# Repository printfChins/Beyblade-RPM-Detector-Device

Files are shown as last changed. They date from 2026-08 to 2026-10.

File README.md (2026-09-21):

(BETA)BRD_0 91OLED_402030_V3 v9

## Beyblade RPM Detector Device

Open-source firmware.

## Flash Download Tool

https://github.com/printfChins/Web-Flash-Download-Tool/tree/main

## Web Interface

Use the BRD Web interface here:

https://printfchins.github.io/BRD-Web/

---

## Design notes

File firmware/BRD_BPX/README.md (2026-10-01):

# BRD_BBPX — LOAD / AUTO 雙模式版

修訂識別：`BRD_BBPX_AUTO`，2026-09-25。以原 `BRD_BBPX` 的 BBPX BLE 協議、單圈曲線與 OLED 圖示為基礎，新增可由 `brd_config.h` 選擇的 **LOAD / AUTO 量測模式**。預設維持 LOAD，避免既有行為在未改 CFG 時改變。

## 開啟與替換方式

完整解壓縮後，以本包的 `BRD_BBPX/` 替換舊專案資料夾，Arduino IDE 開啟 `BRD_BBPX/BRD_BBPX.ino`。根目錄全部 `.cpp/.h` 與 `.ino` 放在同一層。主程式沒有新增片段，不需手動貼入程式。

- Arduino-ESP32 3.3.11；NimBLE-Arduino 2.5.1。
- ESP32C3 Dev Module；CPU 80 MHz；Flash 4 MB、DIO、80 MHz；Default Partition。
- 本次原始碼已變更，但目前環境沒有 Arduino-ESP32 完整編譯工具鏈，因此已移除舊 R4 `.bin`，避免誤燒未包含 AUTO 的舊韌體。
- 請以本包原始碼重新編譯；若要保留 NVS 歷史，停用 Erase All Flash Before Sketch Upload。

## 新增、修改與刪減

| 標記 | 內容 |
|---|---|
| 新增 | `BRD_MEASUREMENT_MODE_LOAD` / `BRD_MEASUREMENT_MODE_AUTO` 與單一 `AUTO_RPM_THRESHOLD=2000`。 |
| 新增 | AUTO 有效歸零：最後有效 RPM < 2000，之後 0 RPM 持續 250 ms。 |
| 新增 | AUTO 有效發射：曾達 RPM >= 2000，之後 0 RPM 持續 1000 ms。 |
| 修改 | AUTO 不掛 LOAD interrupt，也不以 LOAD GPIO 決定開始、發射或歸零。 |
| 修改 | AUTO 的 A0 `loaded` bit：即時 RPM != 0 為 1，RPM == 0 為 0。 |
| 修改 | AUTO OLED 第一行固定 `AUTO READY`；HOLD 仍具有最高顯示優先權。 |
| 保留 | BBPX 既有 32 點單圈曲線格式、Service/Characteristic UUID、17-byte CMD/Notify 封包與 History 格式。 |

本次主要修改 `brd_config.h`、`brd_measurement.cpp`、`brd_oled.cpp`，並新增 AUTO 宿主測試。詳細差異見 `docs/BRD_BBPX_AUTO_MODE.patch`.

## 量測模式設定

模式集中在 `BRD_BBPX/brd_config.h`：

```c
#define BRD_MEASUREMENT_MODE_LOAD         0U
#define BRD_MEASUREMENT_MODE_AUTO         1U
#define BRD_MEASUREMENT_MODE              BRD_MEASUREMENT_MODE_LOAD
#define AUTO_RPM_THRESHOLD                2000U
#define AUTO_LAUNCH_ZERO_MS               1000UL
#define AUTO_RESET_ZERO_MS                250UL
```

| 模式 | READY / 發射來源 | 有效歸零 | 有效發射 | BLE A0 loaded | OLED |
|---|---|---|---|---|---|
| LOAD | LOAD GPIO | 原本 LOAD/timeout 流程 | LOAD HIGH->LOW | 實體 LOAD | `WAIT LOAD` / `LOADED READY` |
| AUTO | RPM-only | `<2000 RPM` 後 0 RPM >=250 ms | 曾 `>=2000 RPM` 後 0 RPM >=1000 ms | RPM!=0 -> 1；RPM==0 -> 0 | `AUTO READY` |

AUTO 達到 2000 RPM 後，250 ms 歸零只會讓即時 RPM 回到 0，不會清掉發射候選；要等 1000 ms 靜止滿足才封存 Shot。AUTO 的 MAX/HOLD 行為沿用 V1.17：完成後顯示 MAX，HOLD 結束仍保留 MAX，直到下一次 RPM 真正開始才清除。

BBPX 協議沒有獨立的「Launch RPM」欄位，因此 AUTO 不新增也不傳送額外發射點 RPM；既有 History 代表值仍維持整次量測 MAX RPM 的 BBPX 測試映射。

## 曲線規則

| 裝載後事件順序 | 本次固定參考 | 每筆曲線的整圈週期 |
|---|---|---|
| 正緣先觸發 | 正緣 | 本次正緣時間－前次有效正緣時間 |
| 負緣先觸發 | 負緣 | 本次負緣時間－前次有效負緣時間 |

第一個參考事件只建立基準；下一個有效同類事件取得整圈週期後，立即記錄。初始 GPIO 電位不決定參考，第一個有效 RPM 來自哪邊也不會改選。同一次量測固定使用相同參考；重新裝載或既有量測重置後才重新選擇。

兩種邊沿仍各用自己的整圈時間計算 `RPM = floor(60000000 / period_us)`。曲線只記錄參考邊沿的 `raw = round(period_us / 8)`，保存前 32 個有效完整週期，尾端補零；第 33 圈之後仍可更新 MAX。發射時保留裝載後的前段曲線。

範例：正緣先到，正緣週期 6000 us、負緣週期 8000 us。即時 RPM 仍會依序更新 10000、7500；曲線只保存正緣的 raw 750，每圈一筆。若負緣先到，則全程保存負緣週期。

連續有效取樣時，32 點代表 32 圈，逐點累加 `raw / 125.0` 得到毫秒時間軸，不再重複累加同一圈。週期仍有 8 us 量化；停頓、被丟棄的無效資料與 raw 飽和不會自動補成絕對時間戳。詳 `docs/SINGLE_REV_REFERENCE.md`。

History 代表 SP 保留整次雙邊沿 MAX RPM 的 BRD 測試映射，可與所選單圈曲線峰值不同，不宣稱等同原廠 SP 評分。發射後完成與至少 600 ms 的發布下限、32 格容量、17-byte BLE 封包均沿用。

## OLED 藍牙圖示

[修改] 完整採用附件 `BRD_BLE_OLED/brd_oled.cpp` 的 `oled_draw_bluetooth_icon()`。圖示為 7×13，位於 x119..125、y17..29；已建立 BLE 連線時顯示，斷線重畫時清除。五位 RPM/MAX 的最右像素為 x105，圖示不遮住文字、HOLD、電池或充電圖示。

預覽在 `docs/OLED_BLE_R4_Preview.png`，左為 R3，右為 R4。影像由實際繪圖函式輸出 framebuffer 後放大，不是 OLED 實板照片。本次已逐點比對，圖示輸出與附件相同。

## API 判定

LOAD 模式沿用原報告相同 30 項條件與 R3 判定：**29 項符合、0 項部分符合、1 項不符合**。AUTO 是 BRD 新增模式，不納入該原協議符合性統計。第 24、26 項已恢復單圈資料與前 32 圈語意；第 27 項原建議「發射後起錄」，本版依你的要求保留「裝載後取得有效週期就起錄」。詳細比對在 `docs/BRD_BBP_API_Conformance_Review.md`。

註解：既有 NVS 曲線不重算，格式沒有 R2／R3 取樣模式欄位；R3 起的新 Shot 採單圈曲線，R4 沿用此規則。

## BLE 與 CMD

| 項目 | 值 |
|---|---|
| 名稱 | `BEYBLADE_TOOL_BRD_XXXX`，`XXXX` = ESP32 eFuse MAC 最後 2 bytes 的四位大寫 HEX |
| Service | `55c40000-f8eb-11ec-b939-0242ac120002` |
| 共用特徵 | `55c4f002-f8eb-11ec-b939-0242ac120002` |
| 特徵屬性 | Notify、Write、Write Without Response |
| 封包 | 固定 17 bytes，多 byte 值為 Little Endian |
| TX 功率 | 0 dBm |

Service 放主廣播，完整名稱放 Scan Response。裝置啟動時使用 `esp_efuse_mac_get_default()` 讀取 ESP32 eFuse MAC，名稱尾碼四碼取 MAC 最後 2 bytes，例如尾碼 `0x126A` 時名稱為 `BEYBLADE_TOOL_BRD_126A`。共用 F002 接收命令是本包實作，原廠 Write UUID 仍未完全確認。

| 一個 byte 命令 | 行為 |
|---|---|
| `0x51` | 回傳一頁 A0。 |
| `0x74` | 依序送 B0~B7、70~73 共 12 頁；可重讀最新完整 Shot。 |
| `0x75` | 清除 RAM 歷史、曲線、MAX、Counter，作廢目前 Capture，安排保存；不增加自創 ACK。 |
| `0x61`／未知 | 安全忽略，不改資料。 |

預設 `BBP_COMPAT_AUTONOTIFY=1` 同時支援命令與事件通知：訂閱穩定 100 ms 後送 A0，loaded 狀態改變送 A0，Shot 發布後送 12 頁。LOAD 模式 A0 byte3 bit2 仍跟隨實體 LOAD；AUTO 模式改為即時 RPM != 0 時為 0x04、RPM == 0 時為 0x00。主機即使每 500 ms 輪詢，也可維持相同封包解析。

`BBP_COMPAT_AUTONOTIFY=0` 只保留舊純輪詢及舊 flags 語意供回歸比對，**不符合預設模式的全部通知條件**。本包無固定每 500 ms 自動 Notify；10 ms 是待送頁面的排程間隔。

12 頁由一致快照產生，傳送中不插入另一批資料。Notify 提交失敗重試同一頁，持續 1.5 秒失敗斷線；32 筆命令佇列溢位也斷線。重新連線或訂閱不續傳舊批次。Notify 成功只表示交給 BLE stack，沒有應用層 ACK；缺頁由主機再送 0x74 整組重讀。

## 歷史與保存

最近 50 筆使用環形緩衝，輸出由舊到新。B6 offsets 7/9/11 分別為終身 MAX、累計次數、有效筆數；B7 byte16 是 B0~B6 的 16-byte payload 總和 mod 256。內部 Counter 為 uint32，BLE 欄位為 uint16，主機需處理 65535 後的回繞。

NVS 使用 `brd_bbp/history_v1`、181-byte version 1 blob 與 CRC32。保留長度、版本、CRC、數值範圍、環形索引及曲線尾端零值檢查；只移除曲線峰值必須等於代表 SP 的假設。舊版有效資料可以載入，既有曲線維持原內容，新收集規則從下一次 Shot 生效。若改回舊韌體，舊解碼器可能拒絕獨立代表值或空曲線的新資料；未承諾降版相容。

Flash 僅在既有安全時段保存。0x75 的 RAM 清除不表示 Flash 已寫入；寫入前突然斷電，尚未保存的結果或清除可能遺失。首次 NVS 載入失敗時不覆寫舊資料，BBP 暫停初始化並重試。無 BLE 連線仍可建立本地歷史。

## GPIO 與既有量測參數

| 功能 | GPIO／設定 |
|---|---|
| RPM IR | 3，INPUT、CHANGE；每次量測第一個觸發邊沿決定固定參考，正緣→正緣或負緣→負緣為一整圈 |
| LOAD IR | 1，INPUT、CHANGE、HIGH=裝載 |
| 電池 ADC | 0，470k/470k 分壓、單次換算 |
| 充電偵測 | 10，INPUT_PULLUP、LOW=充電 |
| 充電 LED | 8 |
| OLED | SDA20／SCL21、外部上拉、128×32 SSD1306 |

LOAD 模式使用 LOAD 穩定 100 ms 才切換；LOAD 只負責歸零與啟動檢測，RPM 開始後不再參與發射判定。BLE 曲線保存最早 32 筆非 0 RPM，MAX 持續獨立更新；即時 RPM 嚴格低於 MAX 的 20% 時完成發射，300 ms 無「本次參考極性」邊沿會把即時 RPM 視為 0。AUTO 模式使用 2000 RPM 單一門檻與 250/1000 ms 歸零/發射時間。兩種模式都保留 MAX 自鎖 2.5 秒、OLED 更新 100 ms、低電與 ADC 錯誤保護。Battery Raw 為 SOC 對應 0~250 的 BRD 映射，非原廠電池標定。

## 資料夾結構與驗證

| 位置 | 內容 |
|---|---|
| `BRD_BBPX/BRD_BBPX.ino` | Arduino 主程式 |
| `BRD_BBPX/*.cpp`、`BRD_BBPX/*.h` | 完整正式模組 |
| `BRD_BBPX/CHANGELOG.md` | 新增／修改／刪減及行號 |
| `BRD_BBPX/VALIDATION.md` | 本次實際測試、編譯結果與限制 |
| `BRD_BBPX/docs/` | API、單圈參考說明、30 項比對、歷史報告、差異與驗證日誌 |
| `BRD_BBPX/firmware/` | 燒錄檔說明；本次未附新 `.bin` |
| `BRD_BBPX/tests/` | 8 組宿主測試及硬體替身 |

完整檔名清單見 `FILE_MANIFEST.txt`。在專案資料夾執行 `python3 tests/run_host_tests.py`；使用 g++ C++17、ASan/UBSan。現為 8 組測試，新增 AUTO 量測回歸；這些測試包含真實協定、Session、量測與 BLE 排程程式，但硬體邊界使用替身，尚未執行實板、無線擷取及官方 App 驗證。

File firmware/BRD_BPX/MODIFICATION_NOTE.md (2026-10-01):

# BRD_BBPX Measurement Modification Note

## 修改檔案
- `BRD_BBPX/brd_config.h`
- `BRD_BBPX/brd_measurement.cpp`
- `BRD_BBPX/tests/test_dual_edge.cpp`
- `BRD_BBPX/BRD_BBPX.ino`
- `BRD_BBPX/README.md`
- `BRD_BBPX/VALIDATION.md`

## 2026-10-01 正/負緣先觸發固定參考

1. RPM GPIO 由 `FALLING` 改回 `CHANGE`。
2. LOAD 模式仍需 LOAD HIGH 穩定 100 ms 才啟動新一輪量測。
3. 量測啟動後，第一個實際 RPM 邊沿決定本次固定參考極性。
4. 若第一個事件為正緣，只使用「正緣 -> 下一個正緣」的完整一圈週期計算 RPM。
5. 若第一個事件為負緣，只使用「負緣 -> 下一個負緣」的完整一圈週期計算 RPM。
6. 同一輪量測中參考極性不會切換；另一極性不更新 RPM、MAX，也不加入 BLE 曲線。
7. 參考極性選定後，ISR 只將相同極性的事件放入 RPM Queue，避免 `CHANGE` 模式長期造成兩倍 Queue 流量。
8. BLE 曲線仍保存最早 32 筆有效 RPM 週期，32 點之後 MAX 仍繼續更新。
9. LOAD 在 SPINNING 後不參與發射判定，也不能重置 RPM/MAX/曲線。
10. LOAD 模式發射完成條件仍為即時 RPM 嚴格小於本次 MAX 的 20%。
11. RPM Queue overflow 時保留本次已選參考極性，只清除週期基準；下一個相同極性邊沿重新建立基準，第二個相同極性邊沿恢復 RPM。

## 未改變
- LOAD 狀態切換仍需穩定 100 ms。
- BLE Profile 容量仍為 32 點。
- MAX 與 32 點曲線仍獨立。
- 300 ms 無參考極性邊沿時，即時 RPM 仍歸零。
- 發射成功條件仍為 `current_rpm < max_rpm * 20%`。
- 先前的 RPM / LOAD Queue overflow 防止中途重置修正仍保留。

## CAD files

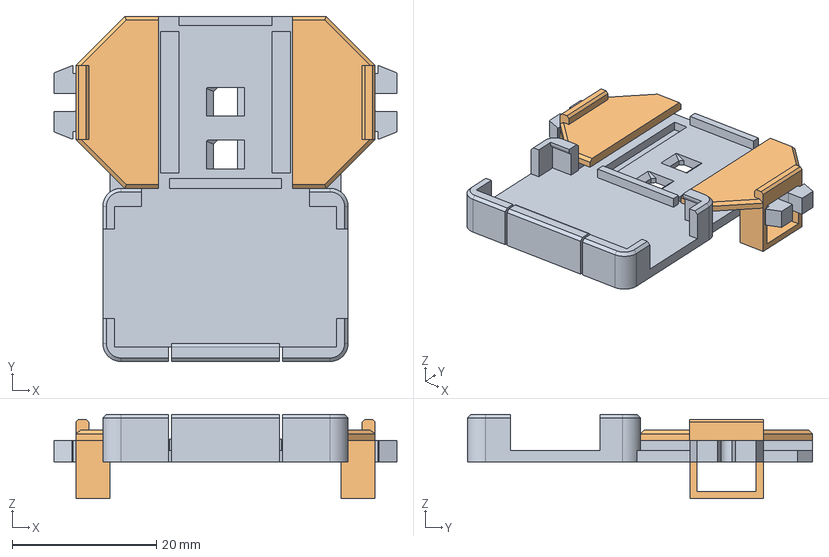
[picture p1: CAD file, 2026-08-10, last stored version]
3D Models/CAD/BRD 1.6mm底板厚度.step
47.5 x 47.8 x 11.7 mm

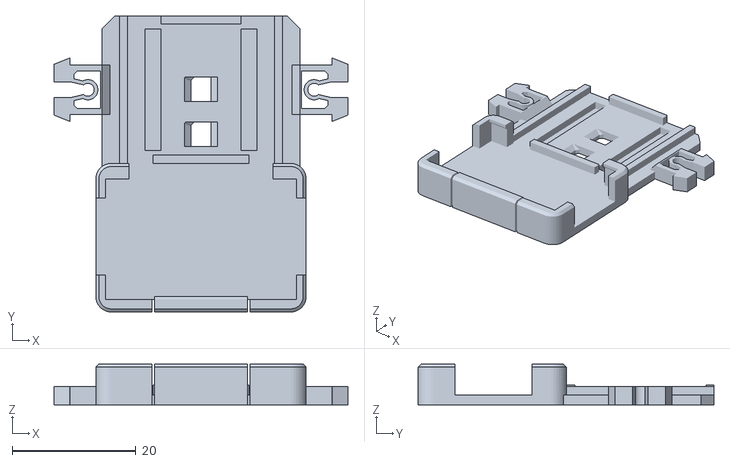
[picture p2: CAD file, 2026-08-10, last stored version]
3D Models/STL/BRD 1.6mm底板厚度_底板.stl
47.5 x 47.8 x 6.60

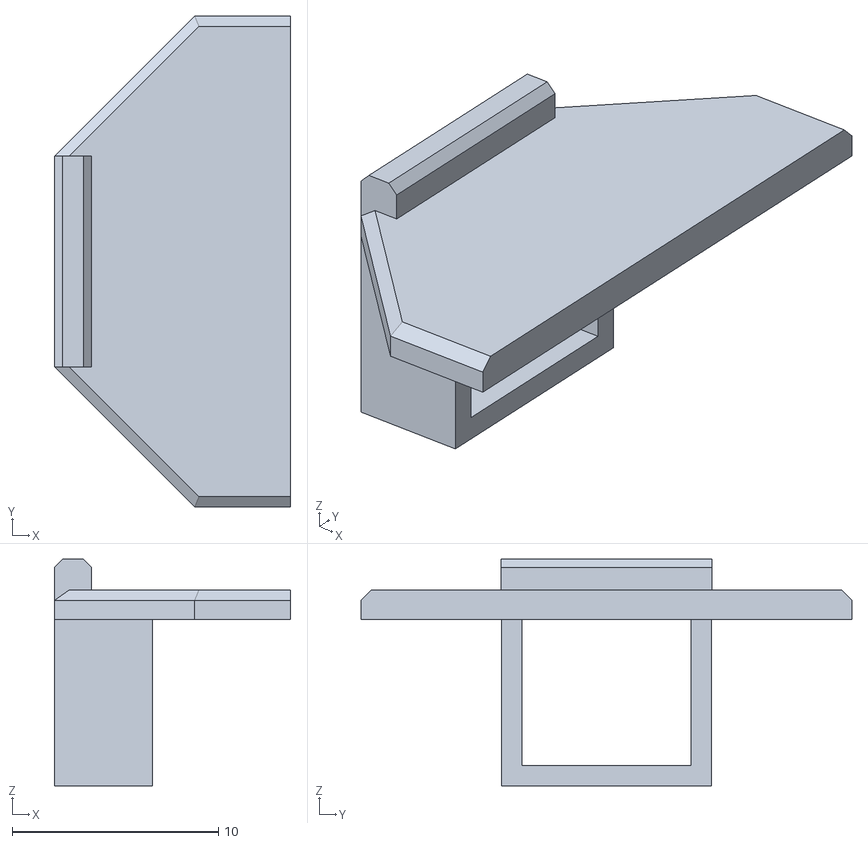
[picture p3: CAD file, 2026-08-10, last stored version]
3D Models/STL/BRD 1.6mm底板厚度_固定夾L.stl
11.4 x 23.8 x 11.0

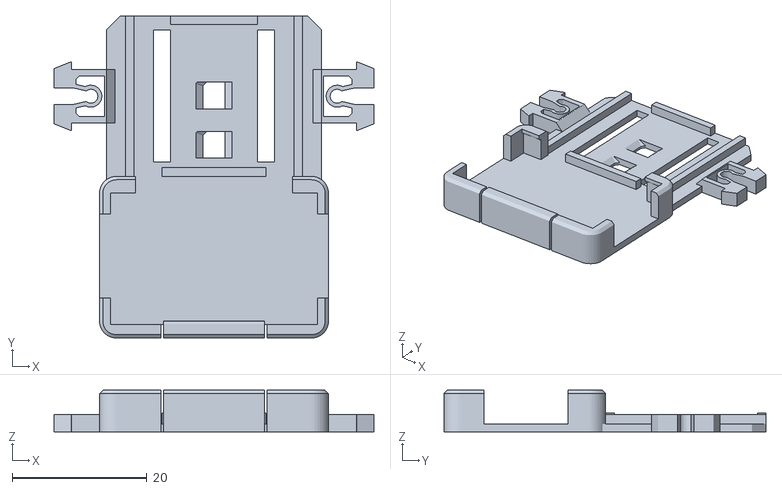
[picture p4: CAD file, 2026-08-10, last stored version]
3D Models/STL/BRD 1.2mm底板厚度_底板.stl
47.5 x 47.8 x 6.20

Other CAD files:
3D Models/STL/BRD 1.2mm底板厚度_固定夾L.stl
3D Models/STL/BRD 1.2mm底板厚度_固定夾R.stl
3D Models/STL/BRD 1.6mm底板厚度_固定夾R.stl

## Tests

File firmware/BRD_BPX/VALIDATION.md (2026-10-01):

# Validation

## 2026-10-01 First-edge reference / dual-edge input

Host regression tests were rebuilt and executed with `-Wall -Wextra -Werror` and ASan/UBSan.

Validated:
- RPM GPIO interrupt mode is `CHANGE`.
- After measurement is armed, the first actual RPM edge selects the reference polarity for that measurement.
- Rising edge first: only rising-to-rising periods calculate RPM.
- Falling edge first: only falling-to-falling periods calculate RPM.
- The opposite polarity does not update instantaneous RPM, MAX, or BLE profile points.
- The selected reference polarity remains fixed for the entire measurement.
- BLE profile still stores only the earliest 32 valid reference-period points.
- MAX continues updating from valid reference periods after the 32-point profile is full.
- RPM queue overflow does not abort the active capture; it preserves the selected reference polarity and rebuilds only the same-polarity period baseline.
- After the reference is selected, ISR filtering only queues that polarity, preventing `CHANGE` mode from permanently doubling RPM queue traffic.
- LOAD state still requires 100 ms stable time and does not reset an active SPINNING measurement.
- LOAD mode still finishes only when instantaneous RPM is strictly below 20% of MAX, including the normal 300 ms no-reference-edge path that sets RPM to zero.

Result: 8/8 host test binaries passed.

Limitations:
- Arduino/ESP32 firmware binary was not regenerated in this environment because Arduino-ESP32 build tools are not installed here.
- No hardware-in-the-loop test was performed.

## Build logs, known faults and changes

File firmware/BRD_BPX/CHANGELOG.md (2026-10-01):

# 2026-10-01 RPM 正/負緣先觸發固定參考

- [修改] `RPM_IR_TRIGGER_EDGE` 由 `FALLING` 改為 `CHANGE`。
- [新增] 每次量測第一個實際 RPM 邊沿決定固定參考極性。
- [修改] 正緣先到：只使用正緣 -> 正緣完整一圈計算 RPM。
- [修改] 負緣先到：只使用負緣 -> 負緣完整一圈計算 RPM。
- [修改] 另一極性不更新 RPM、MAX 或 BLE 曲線，且同一輪量測中不得切換參考極性。
- [修正] 參考選定後 ISR 只將相同極性送入 RPM Queue，避免 `CHANGE` 模式使 Queue 流量長期加倍。
- [保留] RPM Queue overflow 修正：保留既有曲線/MAX/參考極性，只重新建立同極性週期基準。
- [保留] LOAD 100 ms、SPINNING 後忽略 LOAD 發射判定、前 32 點 BLE 曲線、MAX 獨立更新、RPM < MAX 20% 發射成功。
- [驗證] rising-first、falling-first、固定參考、32 點/MAX、20% 門檻與 overflow 參考保持測試通過；8/8 host tests 通過。

# 2026-10-01 採樣中途重置 / Queue Overflow 修正

- [修正] `SPINNING` 後 LOAD HIGH/LOW 僅更新穩定狀態，不得重置 RPM、MAX 或 BLE 曲線。
- [修正] 只有 `WAIT_LOAD` 狀態下，LOAD 穩定 HIGH 100 ms 才能清零並啟動新一輪檢測。
- [修正] RPM ISR Queue overflow 不再呼叫 `brd_bbp_capture_abort()`，保留已取得的前 32 點與 MAX。
- [修正] RPM Queue overflow 後重新建立下降沿基準，禁止用 overflow 前後不連續的邊沿直接計算 RPM。
- [修正] RPM Queue overflow 事件回放期間暫停 inactivity timeout，避免誤觸發 300 ms 歸零/發射完成。
- [修正] LOAD Queue overflow 不再 `reset_measurement(false)` 或重新啟動整個 input capture；只重新同步目前 LOAD 電位並重新做 100 ms 去抖。
- [驗證] 新增 SPINNING LOAD 變化、RPM Queue overflow、LOAD Queue overflow 回歸測試；8/8 host tests 通過。

# 2026-10-01 LOAD 100 ms / 32 點發射判定

- [修改] 所有實體 LOAD 狀態切換需連續穩定至少 100 ms 才更新穩定狀態。
- [修改] LOAD 模式曲線由裝載後第一筆非 0 有效 RPM 開始；該筆 RPM 的邊沿類型成為固定單圈參考，固定保留前 32 點。
- [新增] LOAD 保持裝載且曲線達 32 點時，直接強制判定發射成功並封存。
- [修改] LOAD 已穩定切為非裝載且曲線未滿 32 點時，RPM 降至本次 MAX 的 20% 以下完成發射；300 ms 無脈衝視為 RPM=0。
- [修正] LOAD 卸載的 100 ms 確認期間若才出現有效 RPM，不再誤判為「卸載前未轉動」。

# BRD_BBPX LOAD / AUTO 雙模式修改紀錄

- [修改] BLE 裝置名稱格式改為 `BEYBLADE_TOOL_BRD_XXXX`。
- `XXXX` 取 `esp_efuse_mac_get_default()` 的 ESP32 eFuse MAC 最後 2 bytes，轉成四位大寫 HEX。
- 例如 eFuse MAC 尾碼為 `0x126A`，BLE Scan Response 名稱為 `BEYBLADE_TOOL_BRD_126A`。

日期：2026-09-25。

## 完整檔案與放置位置

專案根目錄：`BRD_BBPX/`

| 檔案 | 標記 | 內容 |
|---|---|---|
| `BRD_BBPX/brd_config.h` | 新增 | `BRD_MEASUREMENT_MODE_LOAD` / `BRD_MEASUREMENT_MODE_AUTO`、`AUTO_RPM_THRESHOLD=2000`、250 ms 歸零及 1000 ms 發射條件。 |
| `BRD_BBPX/brd_measurement.cpp` | 修改 | AUTO 不掛 LOAD 中斷；RPM-only 狀態機、有效歸零/發射判定、MAX/HOLD 行為、AUTO BLE loaded=RPM!=0。 |
| `BRD_BBPX/brd_oled.cpp` | 修改 | AUTO 模式第一行固定顯示 `AUTO READY`，HOLD 優先；補入 U 字型。 |
| `BRD_BBPX/tests/test_measurement_auto.cpp` | 新增 | AUTO 模式宿主回歸測試。 |
| `BRD_BBPX/tests/run_host_tests.py` | 修改 | 增加 AUTO 測試，總數由 7 組增加為 8 組。 |

主程式 `BRD_BBPX/BRD_BBPX.ino` 不需新增程式碼。

## BLE 裝置名稱尾碼

- [修改] 固定名稱 `BEYBLADE_TOOL01` 改為 `BEYBLADE_TOOLXX`。
- `XX` 直接取 `esp_efuse_mac_get_default()` 取得的 ESP32 eFuse MAC 最後 1 byte，轉成兩位大寫 HEX。
- 例如 eFuse MAC 尾碼為 `0x6A`，BLE Scan Response 名稱為 `BEYBLADE_TOOL6A`。
- Service UUID、Characteristic UUID、BBPX 封包與 LOAD / AUTO 模式均不變。

## CFG 模式選擇

`BRD_BBPX/brd_config.h`：

```c
#define BRD_MEASUREMENT_MODE_LOAD         0U
#define BRD_MEASUREMENT_MODE_AUTO         1U
#ifndef BRD_MEASUREMENT_MODE
#define BRD_MEASUREMENT_MODE              BRD_MEASUREMENT_MODE_LOAD
#endif
#define AUTO_RPM_THRESHOLD                2000U
#define AUTO_LAUNCH_ZERO_MS               1000UL
#define AUTO_RESET_ZERO_MS                250UL
```

預設為 LOAD。要使用 AUTO，只需把 `BRD_MEASUREMENT_MODE` 改成 `BRD_MEASUREMENT_MODE_AUTO`。

## AUTO 行為

- RPM < 2000，且之後 0 RPM 持續至少 250 ms：有效歸零。
- RPM 曾 >= 2000，且之後 0 RPM 持續至少 1000 ms：有效發射並封存 Shot。
- 達到 >=2000 後，250 ms 只把即時 RPM 歸零，不清除有效發射候選。
- AUTO 不讀 LOAD 作為量測條件，也不掛 LOAD interrupt。
- AUTO OLED 顯示 `AUTO READY`；HOLD 優先。
- AUTO 預設 BBPX 相容通知中的 A0 loaded bit：RPM != 0 為已裝載，RPM == 0 為未裝載。
- BBPX 沒有獨立 Launch RPM 欄位，因此不新增發射點 RPM 傳輸；History 代表值仍為整次量測 MAX RPM 的既有 BBPX 映射。
- BBPX 曲線格式維持原本 32 個有效完整週期，未加入 0 RPM 起始點，避免 0 被協議解讀為曲線結束。

## 刪減

本次未刪除 LOAD 模式。原本 LOAD 去抖、HIGH->LOW 發射、MAX 20% 結束、300 ms 無脈衝結算都保留。

舊 R4 `.bin` 與完整 4 MB 映像未包含本次 AUTO 修改，已從交付包移除，避免誤燒。

## 2026-10-01 RPM / Launch logic update
- [修改] RPM 計算改為 FALLING -> FALLING，每一整圈只產生一筆 RPM。
- [修改] LOAD 維持 100 ms 穩定判定；LOAD 僅用於歸零及啟動檢測，不參與發射判定。
- [刪減] 移除 >1000 RPM 才開始曲線的限制。
- [刪減] 移除曲線滿 32 點即強制判定發射成功。
- [修改] 第一筆非 0 RPM 起即寫入曲線，BLE 僅保留最早 32 點。
- [修改] MAX 與曲線獨立；曲線滿 32 點後仍持續更新 MAX。
- [修改] 發射成功條件改為即時 RPM 嚴格小於整次 MAX 的 20%。
- [修改] LOAD 卸載後若量測已開始，仍持續依 RPM 判定直到發射成功。

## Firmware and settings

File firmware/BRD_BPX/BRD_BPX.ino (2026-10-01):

/*
    檔案位置: BRD_BBP/BRD_BBP.ino
    貼放位置: 完整主程式，Arduino IDE 開啟此檔，同資料夾保留全部 .cpp/.h。
    [BRD_BBP 修改] 由 BRD_OLED V0.12 整合 BattlePass BLE 周邊端。
    [新增] 電池檢查及開機畫面後才初始化 BLE，再啟動量測。
    [修改] 80MHz、GPIO3 CHANGE；每次量測由先觸發的正/負緣固定為同極性單圈參考。
    [保留] LOAD 100 ms 去抖、20% 結束、2.5 秒 MAX 自鎖。
    [刪減] 不帶入原 OLED build 與 bin，避免誤燒舊韌體。
*/
#include <esp_system.h>
#include "brd_battery.h"
#include "brd_bbp.h"
#include "brd_config.h"
#include "brd_io.h"
#include "brd_measurement.h"
#include "brd_oled.h"
void setup(void) {
    setCpuFrequencyMhz(CPU_FIXED_FREQ_MHZ);
    brd_io_begin();
    brd_battery_begin();
    brd_oled_begin();
    brd_battery_update();
    if (brd_battery_measurement_allowed()) {
        brd_bbp_begin();
        brd_battery_update();
    }
    if (brd_battery_measurement_allowed()) {
        brd_measurement_begin();
    } else {
        brd_measurement_stop();
        brd_bbp_stop();
    }
}
void loop(void) {
    brd_battery_update();
    if (!brd_battery_measurement_allowed()) {
        brd_measurement_stop();
        brd_bbp_stop();
        /* [修正] SOC 恢復穩定後先保存 dirty 紀錄，成功才重啟，避免清除被撤回。 */
        if (brd_battery_restart_required() && brd_bbp_prepare_restart()) {
            esp_restart();
        }
        brd_oled_update();
        delay(BATTERY_LOW_LOOP_DELAY_MS);
        return;
    }
    brd_measurement_begin();
    /* [保留] 量測事件優先，其次 BLE，最後 OLED 一個區塊。 */
    brd_measurement_update();
    bool storage_allowed = brd_measurement_storage_allowed();
    if (storage_allowed) {
        brd_bbp_begin();
    }
    brd_bbp_update(storage_allowed);
    brd_oled_update();
    delay(MAIN_LOOP_DELAY_MS);
}

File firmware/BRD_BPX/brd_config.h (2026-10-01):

/*
    檔案位置: BRD_BBP/brd_config.h
    [V0.10 修改] 單機 OLED 轉速版本。硬體腳位沿用附件 V1.9。
    [V0.10 刪減] BLE、休眠與曲線封包參數。
    [V0.10 恢復] 電池 ADC 取樣與 OLED 電量、充電圖示。
    [V0.10 新增] 低電鎖定、沒電警示及恢復後重新啟動。
*/
#ifndef BRD_CONFIG_H
#define BRD_CONFIG_H

#include <Arduino.h>
#include <esp_idf_version.h>
#include <hal/adc_types.h>

#if !defined(CONFIG_IDF_TARGET_ESP32C3)
#error "Select ESP32C3 Dev Module for this project."
#endif
#if ESP_IDF_VERSION < ESP_IDF_VERSION_VAL(5, 3, 0)
#error "This project requires Arduino-ESP32 with ESP-IDF 5.3 or newer."
#endif

#define PROJECT_FULL_NAME                 "Beyblade RPM Detector BattlePassX"
#define PROJECT_SHORT_NAME                "BRD"
#define PROJECT_VERSION                   "BPX V1.0"
#define CPU_FIXED_FREQ_MHZ                80U
#define MAIN_LOOP_DELAY_MS                1UL

/*
    [修改] BLE 裝置名稱改為固定前綴 + ESP32 eFuse MAC 最後 2 bytes。
    實際名稱由 brd_bbp.cpp 在啟動時建立，例如 eFuse MAC 尾碼 0x12AF -> BEYBLADE_TOOL_BRD_12AF。
*/
#define BBP_DEVICE_NAME_PREFIX            "BEYBLADE_TOOL_BRD_"
#define BBP_SERVICE_UUID                  "55c40000-f8eb-11ec-b939-0242ac120002"
#define BBP_CHARACTERISTIC_UUID           "55c4f002-f8eb-11ec-b939-0242ac120002"
#define BBP_TX_POWER_DBM                  0
#define BBP_COMMAND_QUEUE_SIZE            32U
#define BBP_NOTIFY_INTERVAL_MS            10UL
#define BBP_NOTIFY_TIMEOUT_MS             1500UL
#define BBP_RETRY_INTERVAL_MS             1000UL
/*
    [BRD_BBP 修正 新增] 預設對應使用者確認可用的 V0.1 主動通知流程。
    1: 訂閱後、LOAD 改變送 A0，發射紀錄完成送 B0~B7 / 70~73。
       A0 bit2 表示去抖後的 LOAD，與該可用版本一致。
    0: 嚴格依 battlepass-emulation.md，僅回覆 0x51 / 0x74；
       bit2 仍表示有效轉動至結果發布前，不表示靜態 LOAD。
    [刪減] 不再把純輪詢設為所有上位機共用的唯一流程。
*/
#ifndef BBP_COMPAT_AUTONOTIFY
#define BBP_COMPAT_AUTONOTIFY              1
#endif
#define BBP_SUBSCRIBE_SETTLE_MS            100UL
static_assert(BBP_COMPAT_AUTONOTIFY == 0 || BBP_COMPAT_AUTONOTIFY == 1,
              "BBP compatibility mode must be 0 or 1.");
/* [新增] 有效轉動起的發布下限；量測尚未結束時仍繼續等待。 */
#define BBP_PUBLISH_MIN_DELAY_US          600000UL
/* [新增] BRD 鋰電池 SOC 門檻，非聲稱已確認原廠 AAA 門檻。 */
#define BBP_BATTERY_WARNING_PERCENT       20U
#define BBP_BATTERY_CRITICAL_PERCENT      5U
#define BBP_NVS_NAMESPACE                 "brd_bbp"
#define BBP_NVS_KEY                       "history_v1"
static_assert(BBP_COMMAND_QUEUE_SIZE > 0U && BBP_COMMAND_QUEUE_SIZE <= 256U,
              "Invalid BBP command queue size.");
static_assert(BBP_NOTIFY_INTERVAL_MS > 0UL && BBP_NOTIFY_INTERVAL_MS < 40UL,
              "12 BBP pages must fit inside a 500ms poll interval.");
static_assert(BBP_PUBLISH_MIN_DELAY_US < 2000000UL,
              "Publish must fit inside OLED hold interval.");
static_assert(BBP_BATTERY_CRITICAL_PERCENT <= BBP_BATTERY_WARNING_PERCENT &&
              BBP_BATTERY_WARNING_PERCENT <= 100U, "Invalid BBP battery thresholds.");

/* [V0.10 修改] RPM、LOAD 與 ADC 不啟用內部上下拉；充電 DET 例外使用上拉。 */
#define RPM_IR_GPIO                       3
#define RPM_IR_INPUT_MODE                 INPUT
/* [修改] RPM 使用 CHANGE 捕捉正、負緣；本次量測第一個觸發邊沿決定固定參考極性。
    先正緣：正緣 -> 正緣計算一圈 RPM；先負緣：負緣 -> 負緣計算一圈 RPM。 */
#define RPM_IR_TRIGGER_EDGE               CHANGE
#define LOAD_IR_GPIO                      1
#define LOAD_IR_INPUT_MODE                INPUT
#define LOAD_IR_TRIGGER_EDGE              CHANGE
#define LOAD_ACTIVE_LEVEL                 HIGH
#define BATTERY_ADC_GPIO                  0
#define CHRG_DET_GPIO                     10
/* [V0.10 修正] 充電 DET 沿用原電路 LOW=充電、滿電高阻，恢復內部上拉。 */
#define CHRG_DET_INPUT_MODE               INPUT_PULLUP
#define CHRG_ACTIVE_LEVEL                 LOW
#define STATUS_LED_GPIO                   8
#define STATUS_LED_INACTIVE_LEVEL         HIGH

/*
    [V0.10 恢復] 沿用 V1.9 電池量測設定。
    GPIO0 / A0，470k / 470k 分壓；12-bit、11 dB attenuation。
    [修改] 每 1 秒單次讀取 ADC mV 並直接換算，供低電即時判斷。
    不加入平均或 IIR 濾波。
*/
#define BATTERY_ADC_RESOLUTION_BITS       12U
/* [V0.12 修改] 原 ADC_11db 對應相同硬體衰減檔位，改用原生 IDF 名稱。 */
#define BATTERY_ADC_ATTENUATION           ADC_ATTEN_DB_12
#define BATTERY_DIVIDER_R_TOP_OHM         470000UL
#define BATTERY_DIVIDER_R_BOTTOM_OHM      470000UL
#define BATTERY_MIN_MV                   3300U
#define BATTERY_MAX_MV                   4200U
#define BATTERY_SAMPLE_INTERVAL_MS        1000UL
#define BATTERY_CALIBRATION_NUMERATOR     1000UL
#define BATTERY_CALIBRATION_DENOMINATOR   1000UL
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

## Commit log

2026-08-10 Add 3D Models、firmware
    [BRD 1.2mm底板厚度_固定夾L.stl, BRD 1.2mm底板厚度_固定夾R.stl, BRD 1.2mm底板厚度_底板.stl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]
2026-09-10 refactor: 重構韌體目錄，新增 BRD_BLE, BRD_OLED, BRD_BLE_OLED
2026-09-10 feat(OLED): 在 test 分支，修改OLED HOLE TIME
2026-09-10 新增 IR 測試FW bin
2026-09-11 新增 低電警示
2026-09-11 新增發射後HOLD延遲，修改版號V0.11
2026-09-11 新增燒錄檔
2026-09-11 FW V0.11
    [BRD 1.2mm底板厚度.step, BRD 1.2mm底板厚度_固定夾L.stl, BRD 1.2mm底板厚度_固定夾R.stl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]
2026-09-15 V0.15 BLE功能測試正常
